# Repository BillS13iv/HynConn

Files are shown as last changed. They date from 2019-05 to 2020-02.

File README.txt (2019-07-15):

NOTICE: I do NOT guarantee anything on this connector.  It is up to you to ensure the fitment, rigidity, and design with your setup.  I take no ownership of any damage you may do.

NOTES ON CONNECTORS: Pricing shown is that at Shapeways.com for Fine Detail Plastic with Smoothest Finish.
Information on the material can be found here: https://www.shapeways.com/materials/fine-detail-plastic.
The polymer (for fine detail plastic) is a poly-acrylic that is rated for 133F (56C), but has poor UV resistance .
It is recommended that if you believe the connector may be exposed to sun light, to coat the outside of the connector in a UV-resistant coating such as Krylons UV-resistant clear coat (https://www.krylon.com/products/uvresistant-clear-coating/).
The .stl files have been optimized and are ready to be sent to a printing service.
The .skp are Sketchup files (version 2018 or later) that can be used to modify the connector if need be.
If you change the connector design, it is recommended to optimize the drawing using a service like those by MakePrintable (https://makeprintable.com/) to optimize the .stl.  You may find this optimization will reduce printing costs significantly.

-----------------------------------------------------------------------------------------

The male connector designed to work with socket strips are also made by SamTec.
You will need:
Quantity: 1, Model: ESQT-108-02-F-S-309
https://www.samtec.com/products/ESQT-108-02-F-S-309
Quantity: 1, Model: MTMM-108-15-T-S-541
https://www.samtec.com/products/mtmm-108-15-t-s-541
Quantity: 2, Model: ESQT-102-02-F-S-309
https://www.samtec.com/products/ESQT-102-02-F-S-309
Quantity: 2, Model: MTMM-102-15-T-S-541
https://www.samtec.com/products/mtmm-102-15-t-s-541

The 7mm end (shorter end) is loaded into the connector.  The longer end is used for connecting wires.

-----------------------------------------------------------------------------------------

The female connector uses receptacles made by TE:
You will need:
Quantity: 14 to 24, Model: 2-1703930-1
https://www.te.com/usa-en/product-2-1703930-1.html

-----------------------------------------------------------------------------------------

For wire, the connectors are desiged for 26 gauge space-saver wire, with an outer diameter of 0.05"
https://www.mcmaster.com/8054t11

Wire Gauge 	26
Current	5 A @ 86° F
Voltage	300V AC
Temperature Range	-40° to 220° F
OD	0.05"

Or for 24 gauge standard wire, with an outer diameter of 0.05"
https://www.mcmaster.com/8251t1

Wire Gauge 	24
Current	7 A @ 86° F
Voltage	300V AC
Temperature Range	-40° to 220° F
OD	0.05"

-----------------------------------------------------------------------------------------

Printing was completed using an outside 3D printing service, I would recommend Shapeways.
Connectors are printed in "Smoothest - Fine Detail Plastic".

-----------------------------------------------------------------------------------------

Older Design: Quantity: 1, Model: MTMM-108-14-T-S-276 Quantity: 2, Model: MTMM-102-14-T-S-276

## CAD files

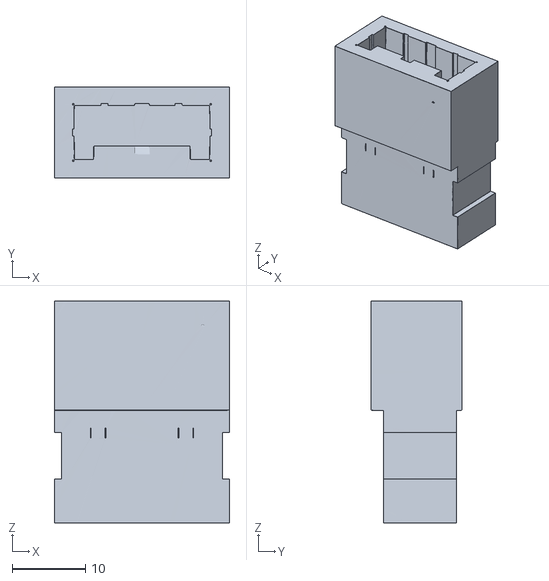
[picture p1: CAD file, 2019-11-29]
Male Connector - Fixed - 11.29.19.stl
24.0 x 12.5 x 30.4

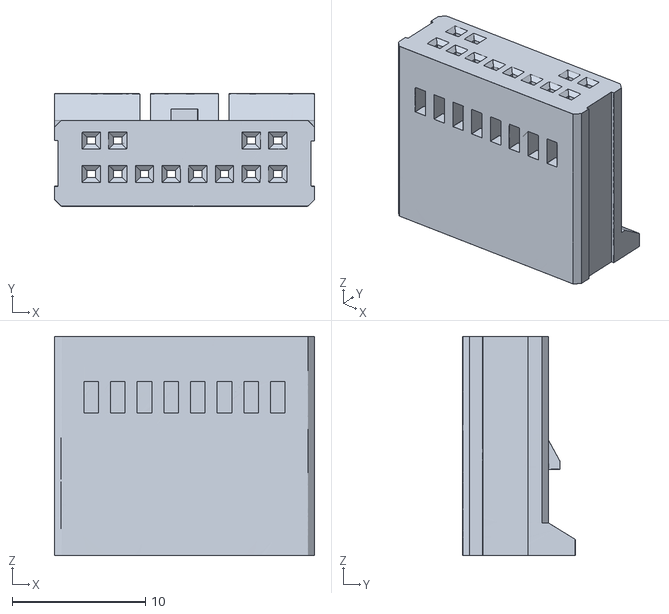
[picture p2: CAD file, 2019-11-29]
Female with Tab - Fixed - 11.29.19.stl
19.5 x 8.44 x 16.5

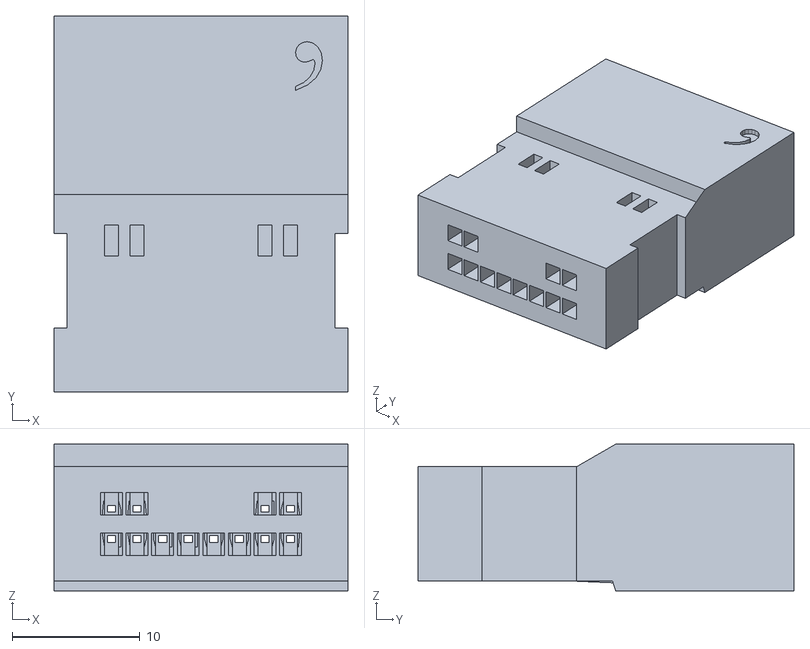
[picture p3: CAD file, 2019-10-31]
Male Connector Socket - With Crimps - 10.31.obj
23.0 x 29.4 x 11.5

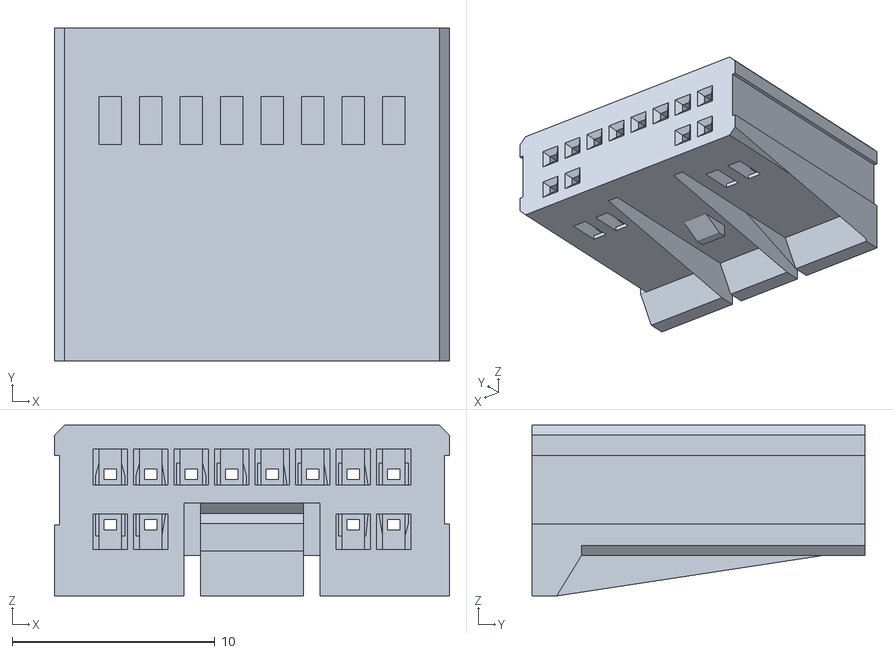
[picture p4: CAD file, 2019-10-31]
Female Connector - Tab - 10.31.19.obj
19.5 x 16.5 x 8.44

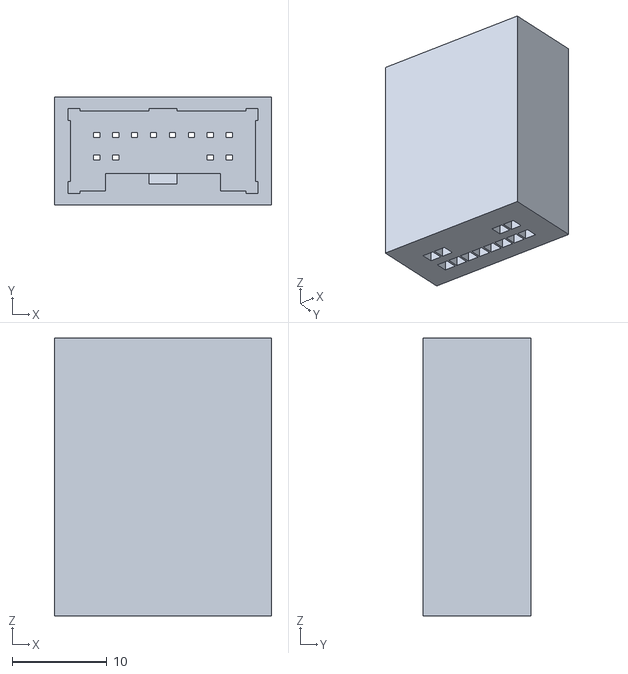
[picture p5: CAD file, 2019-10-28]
Male Connector Socket - Wire Pin Crimps.stl
23.0 x 11.5 x 29.4

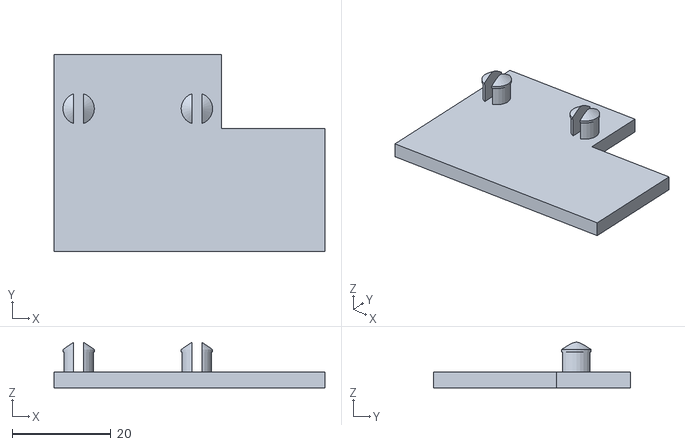
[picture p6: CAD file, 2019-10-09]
New Back Plate.stl
55.0 x 40.0 x 9.27

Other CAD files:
Female Connector - No Tab - 10.31.19.obj
Female with Tab - Fixed - 11.29.19.obj
Male Connector - Fixed - 11.29.19.obj
Male Connector Socket - 4.29.19.skp
Male Connector Socket - With Crimps - 10.31.19.skp

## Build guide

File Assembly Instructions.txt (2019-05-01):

rTools Required:
* A heat gun or hair dryer
* A crimping tool for Dupont pins (a ratcheting set is preferred)
* A set of wire strippers, also a straight pair of tin snips may be useful for cutting pins
* A small metal pick
* 24 gauge wire heat shrink (7 x ½” (13mm) long pieces)

To Note:
The phrase “receptacle” will refer to the part 2-1703930-1, the TE Receptacle Terminal
The phrase “socket head” will refer to parts ESQT-108-02-F-S-309 and ESQT-102-02-F-S-309, made by Samtec
The phrase “terminal head” will refer to parts MTMM-108-15-T-S-541 and MTMM-102-15-T-S-541 made by Samtec

-------------------------------------------------------------------------------

1) Start by cutting the wire into 6” to 12” (15 cm to 30 cm) lengths; a total of strips 14 are needed
2) Strip off 1/8th of an inch of insulation (2.5 mm) on each wire
3) Insert the wire ~7/32” (5.5 mm) onto the wire receptacle
4) Crimp the wire onto the receptacle using the crimping tool
a. NOTE: For the ratcheting crimping tool, it is easiest to close the mouth of the tool until the receptacle barely fits into the teeth.  This will hold the receptacle in place to align the wire and squeeze the tool.
5) Repeat for the other 13 wires
6) Inspect the 3D printed connectors and verify that all the hole are clear.  A 0.197” (0.5 mm) drill bit can be used to clear out any closed holes on the male connector.

Female Connector:
1) Insert the crimped wires into the backside of the 3D printed connectors with the spring portion of the connector facing outward.  Based on what side of the connector you are loading the receptacle, you may have to flip the receptacle
2) Using the pick, push the receptacle to the front of the female housing; there is a small chamber on the housing were the receptacle spring should lift, locking it into place
3) Loosely tug onto the wire to ensure the spring has fully lifted, and the receptacle will not come out of the housing
4) Repeat for the next 6 wires

Male Connector:
1) Inset the socket heads into the backside of the male connector and light push the the the socket heads until the pin are exposed on the front of the male housing, all 3 socket head should be inserted into the housing before continuing
2) Using a padded vise or pushing on the backside of the connector using a surface, continue to move the socket head until only ~1/8” (or 3 mm) remains exposed
3) Place the pieces on heat shrink on the remaining 7 wires, the end of the heat shrink should be flush with the receptacle ends so that the receptacle is fully covered
4) Using the heat gun, shrink the heat shrink onto the receptacle
a. NOTE: This can be done either before or after attaching the connector to terminal heads (step 7).  Caution should be used not to destroy the terminal heads with the heat gun if this is done.
5) Insert the long end of the terminal heads into the socket heads and note the gap between the spacer on the terminal head and the socket head (the gap should be around ~6mm in length or ~1/4”)
6) Remove the terminal heads from the socket heads, and using the wire cutters or tin snips, cut the pins to remove the gap distance (between 5 and 8 mm)
7) Attach the receptacles to the uncut end of the terminal head pins
8) Reinsert the cut end of the terminal head back into the socket head
9) Use a heat resistant, non-expanding glue to secure all components (terminal heads, socket heads, receptacles).

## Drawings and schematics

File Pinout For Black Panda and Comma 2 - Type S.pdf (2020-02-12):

# Type S KET

## GRND

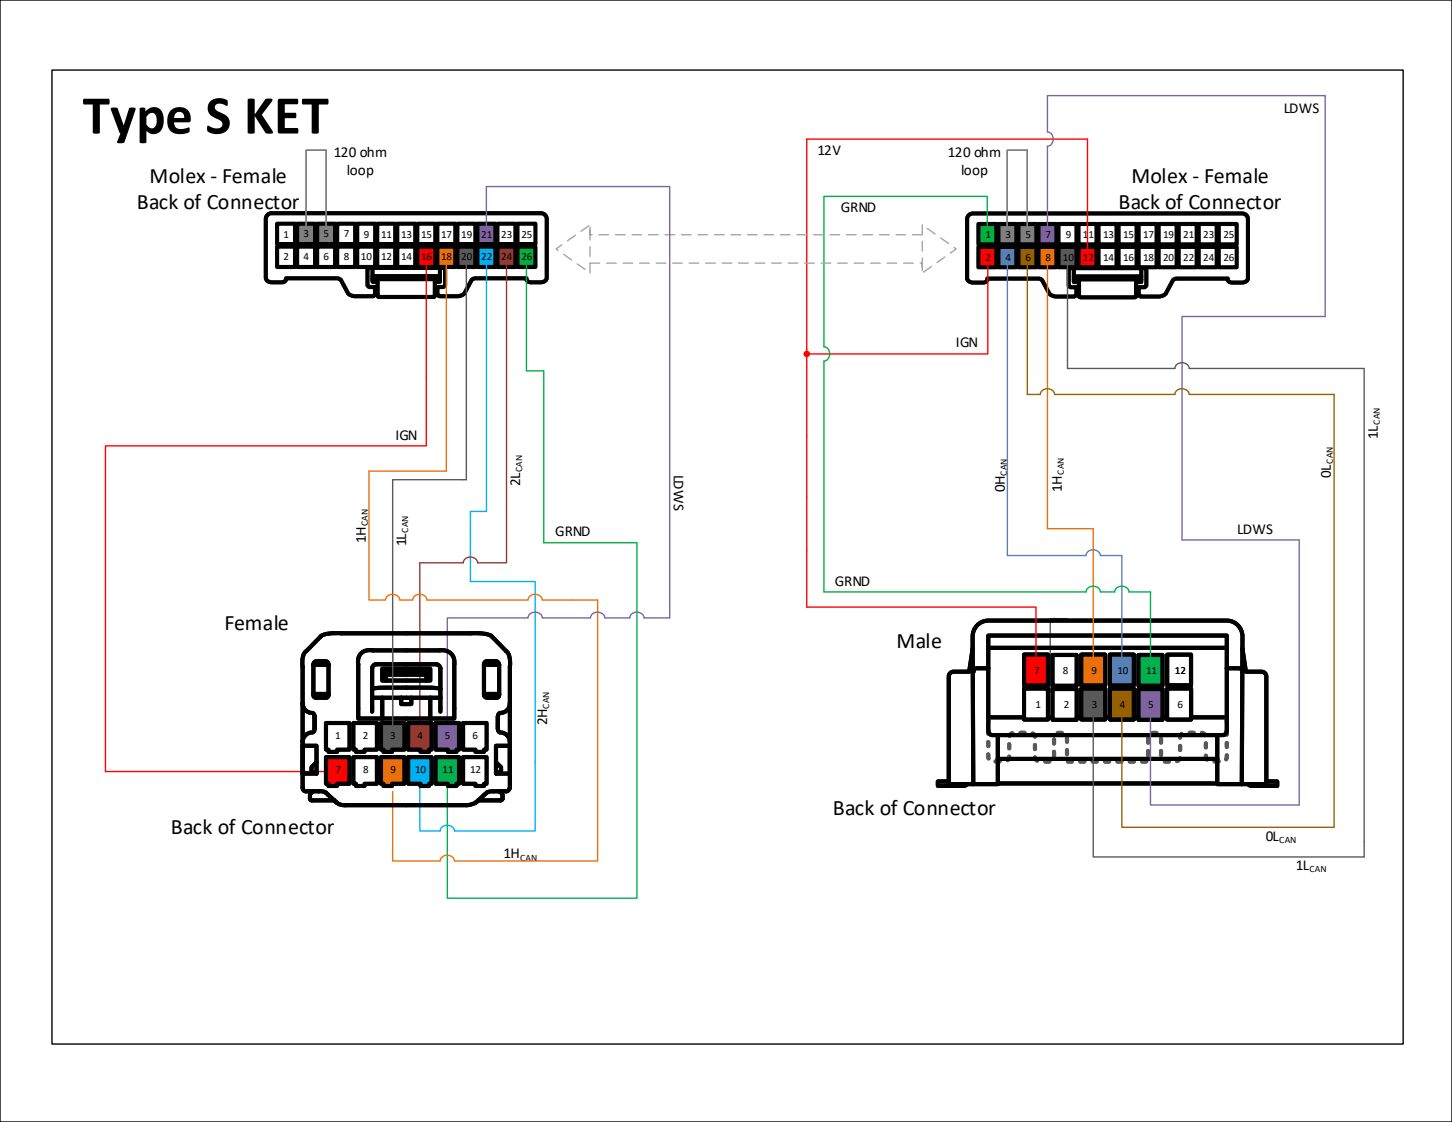
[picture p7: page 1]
GRND; IGN1LCAN; IGN; Female; Male; 120 ohm loop; LDWS; 1HCAN; 2HCAN; 2LCAN; 0LCAN; 1LCAN; 0HCAN

Molex - Female
Back of Connector

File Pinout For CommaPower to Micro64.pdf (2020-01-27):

# Comma Power RJ45 to Micro 64 8W

## IGN

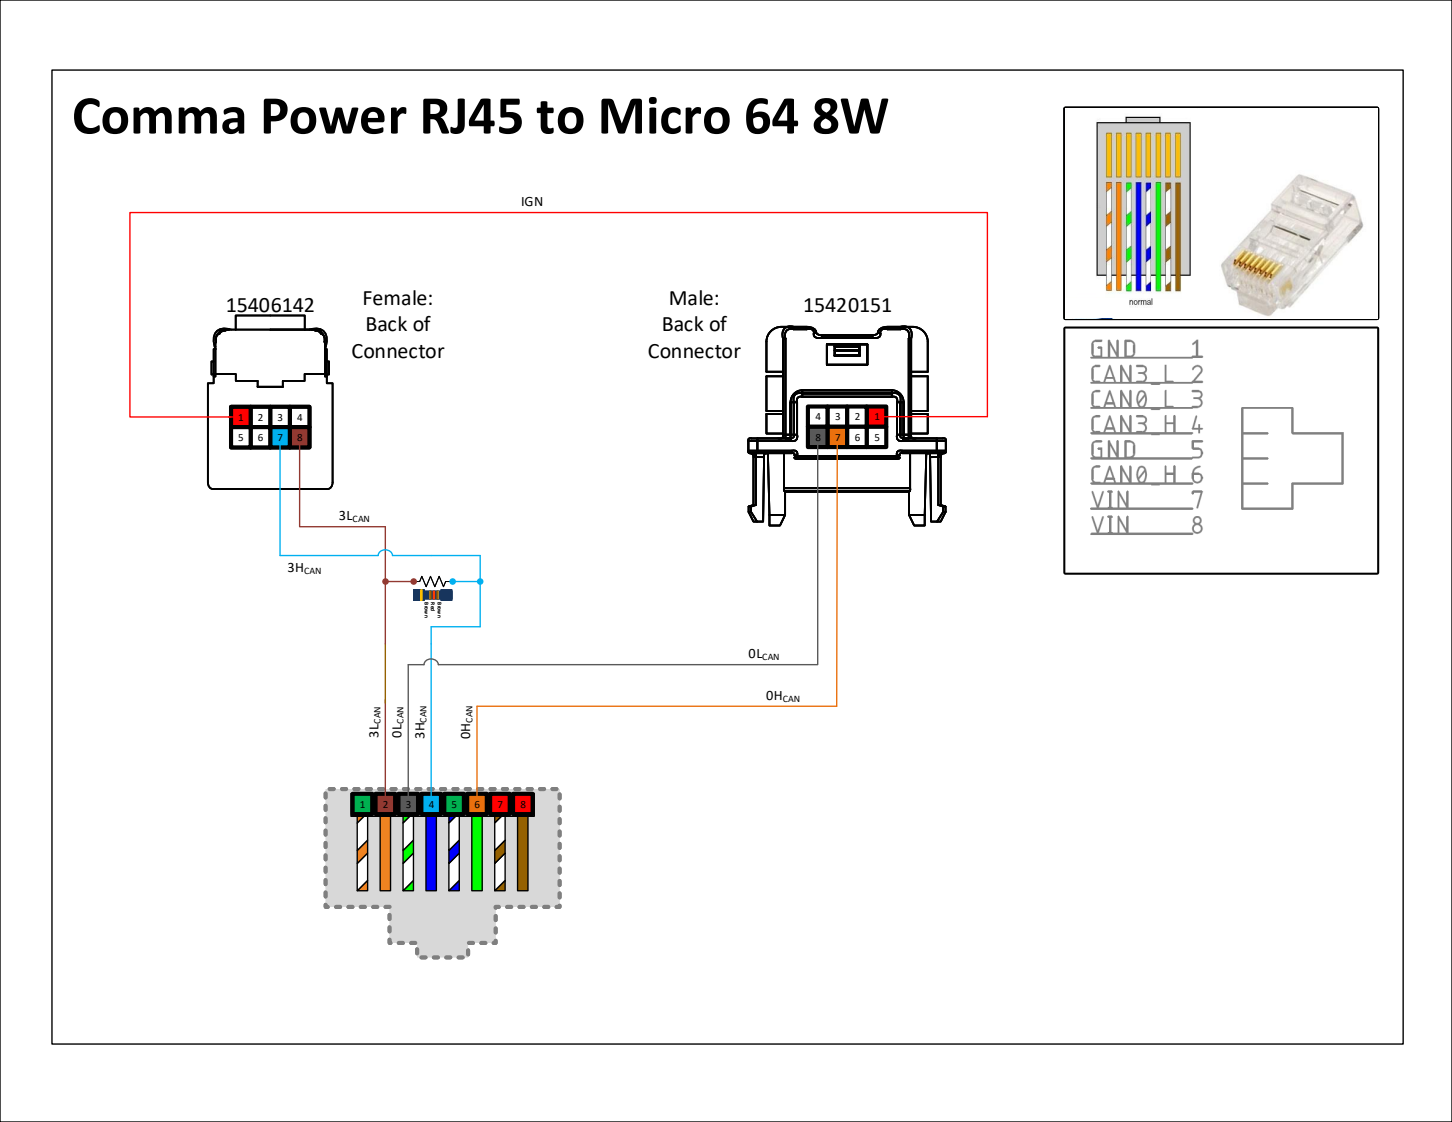
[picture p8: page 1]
8 ³LCAN; 0LCAN; 3HCAN; 0HCAN; 3LCAN; Male: Back of Connector

Female:
Back of
Connector Brown Red Brown

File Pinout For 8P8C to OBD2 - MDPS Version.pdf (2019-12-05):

# 8P8C to OBD2 – MDPS Version

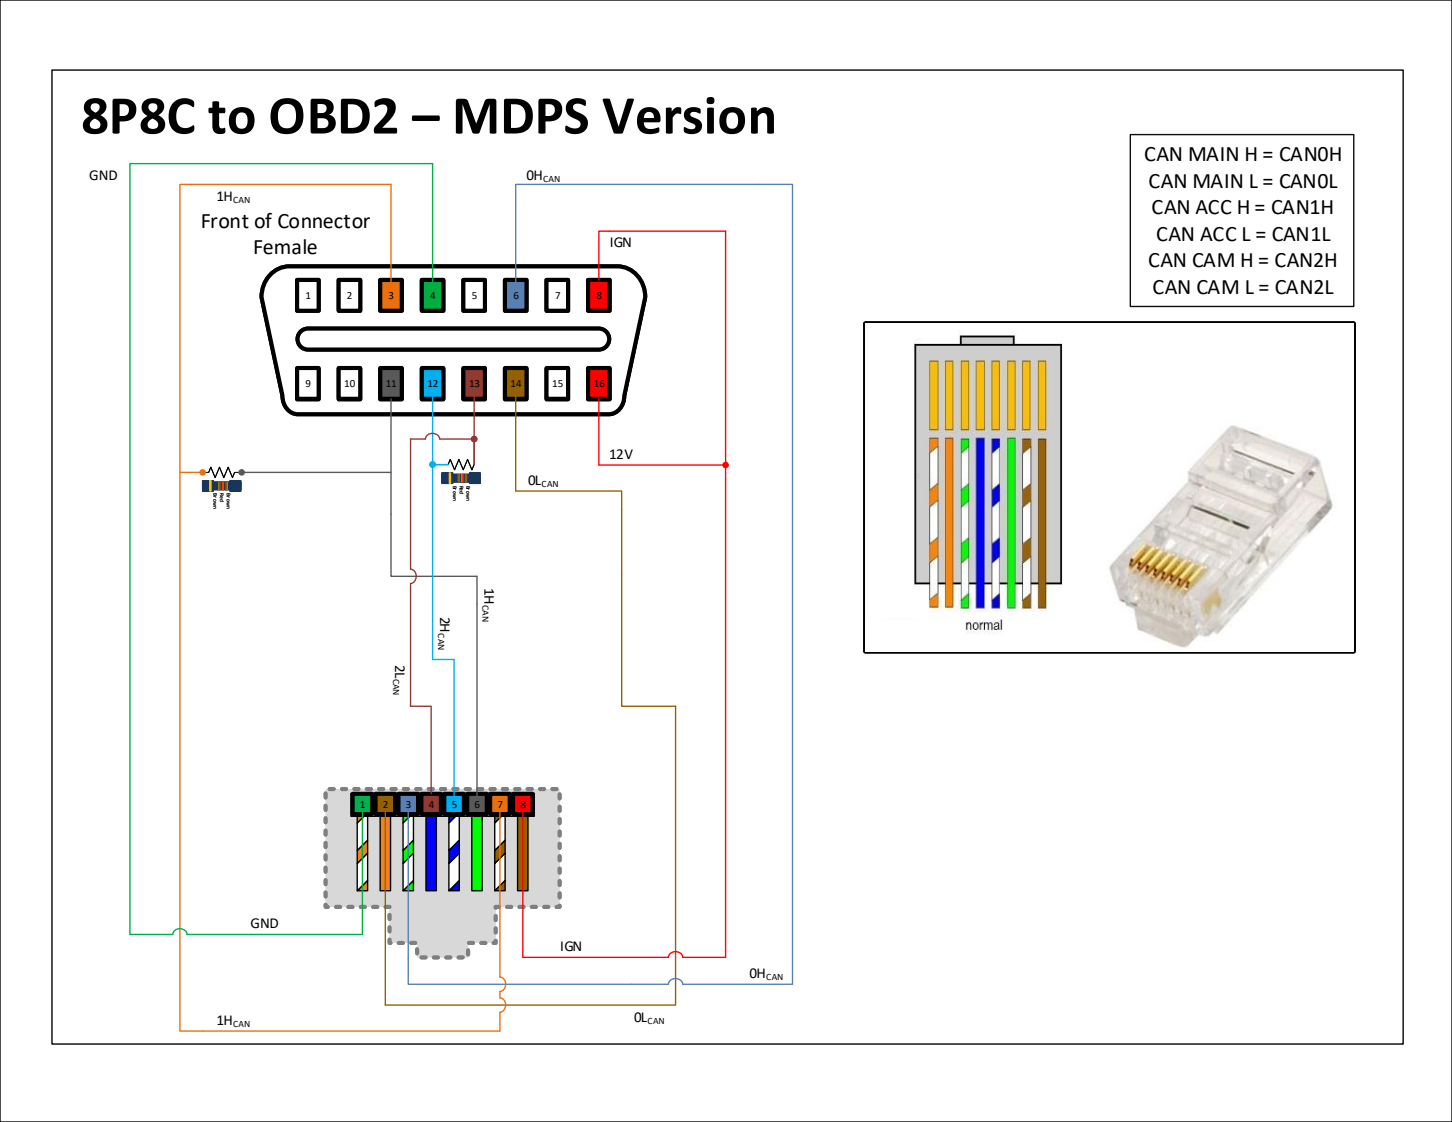
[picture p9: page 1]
CAN MAIN H = CAN0H CAN MAIN L = CAN0L CAN ACC H = CAN1H CAN ACC L = CAN1L CAN CAM H = CAN2H CAN CAM L = CAN2L; IGN; 8 Br own Red Br own; Front of Connector Female; 1HCAN; 0HCAN; 0LCAN; GND; 2LCAN; 2HCAN; Br own; Red

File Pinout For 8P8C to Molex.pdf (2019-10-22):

# 8P8C to Molex

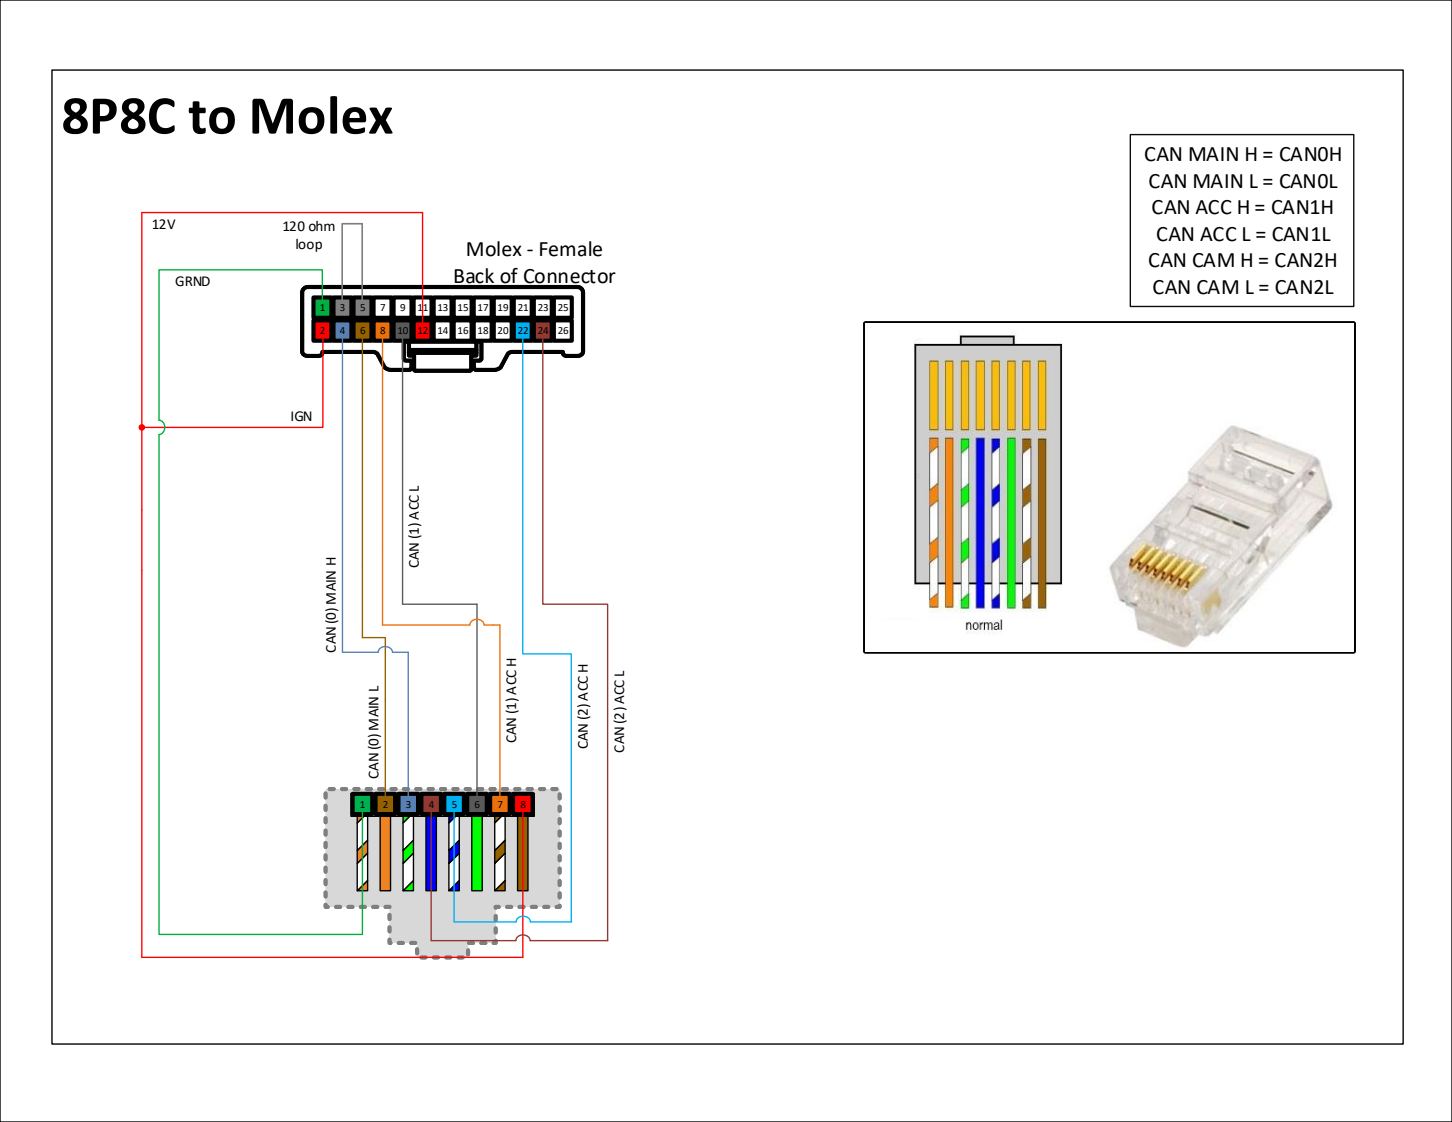
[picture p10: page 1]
CAN MAIN H = CAN0H CAN MAIN L = CAN0L CAN ACC H = CAN1H CAN ACC L = CAN1L CAN CAM H = CAN2H CAN CAM L = CAN2L; GRND; IGN; - Female; CAN (1) ACC L; CAN (0) MAIN L; CAN (2) ACC H; CAN (0) MAIN H; 120 ohm loop; CAN (1) ACC H; CAN (2) ACC L

Molex
Back of Connector

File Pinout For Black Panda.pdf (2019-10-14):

# Type I KET

## GRND

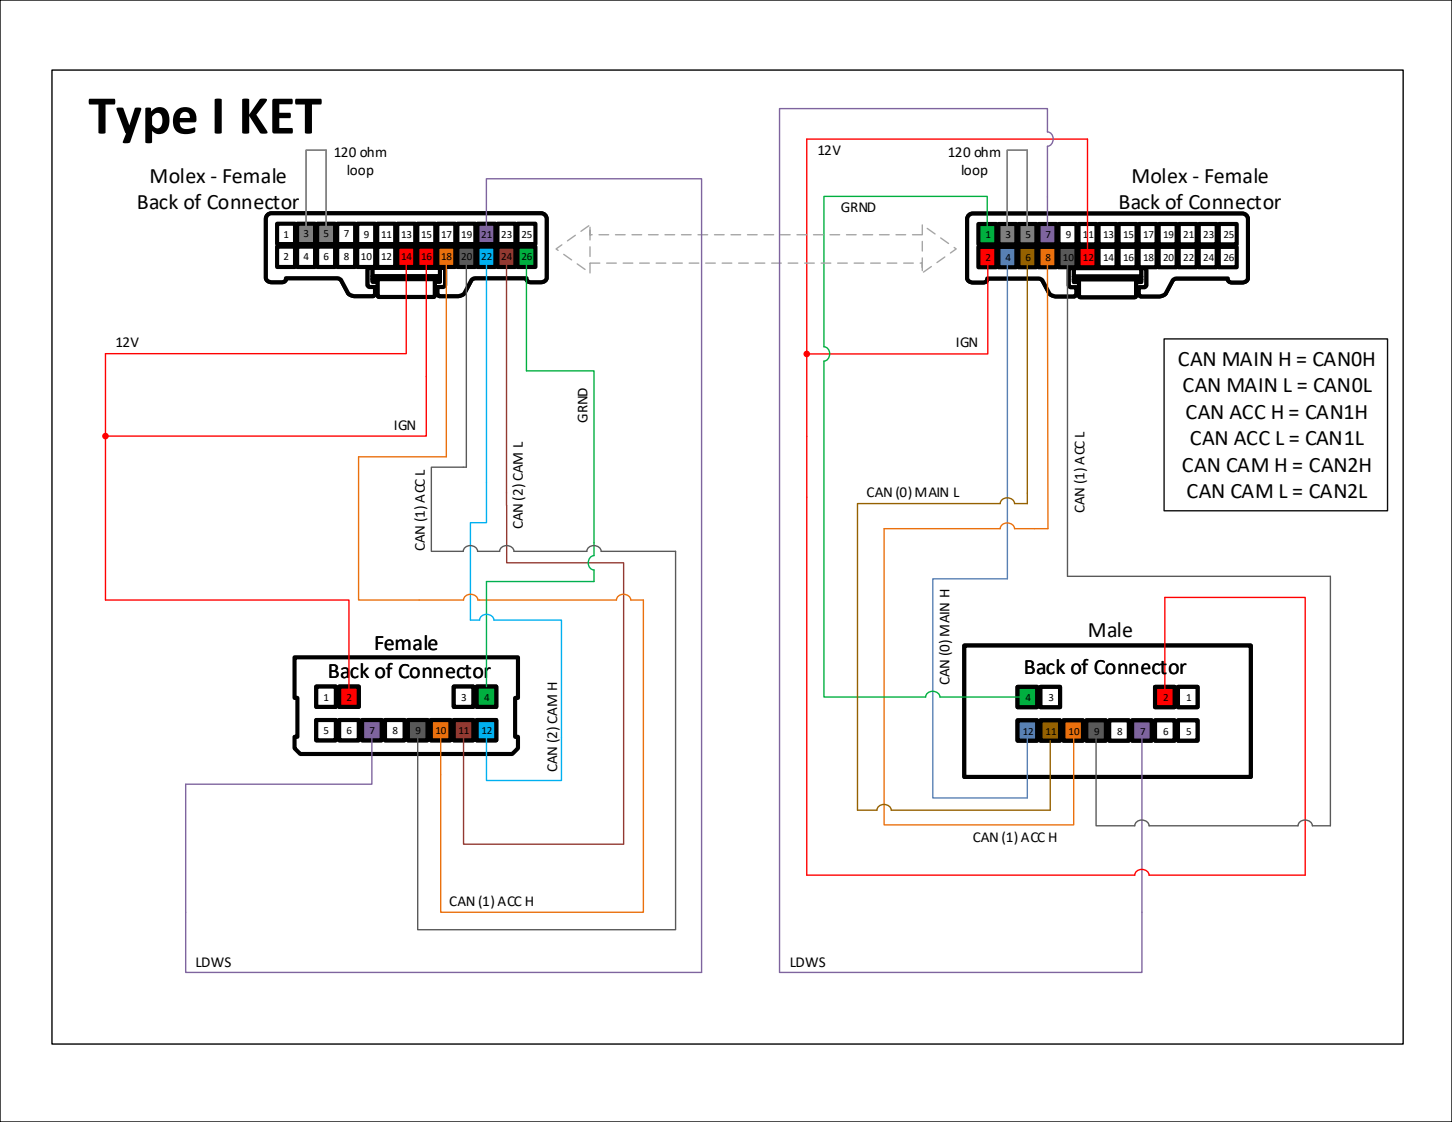
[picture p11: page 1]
CAN MAIN H = CAN0H CAN MAIN L = CAN0L CAN ACC H = CAN1H CAN ACC L = CAN1L CAN CAM H = CAN2H CAN CAM L = CAN2L; GRND; IGN; CAN (2) CAM H; CAN (1) ACC H; CAN (1) ACC L; CAN (2) CAM L; CAN (0) MAIN L; CAN (0) MAIN H; Female; Male; Back of Connector; 120 ohm loop; LDWS

Molex - Female
Back of Connector

# Type II KET

## GRND

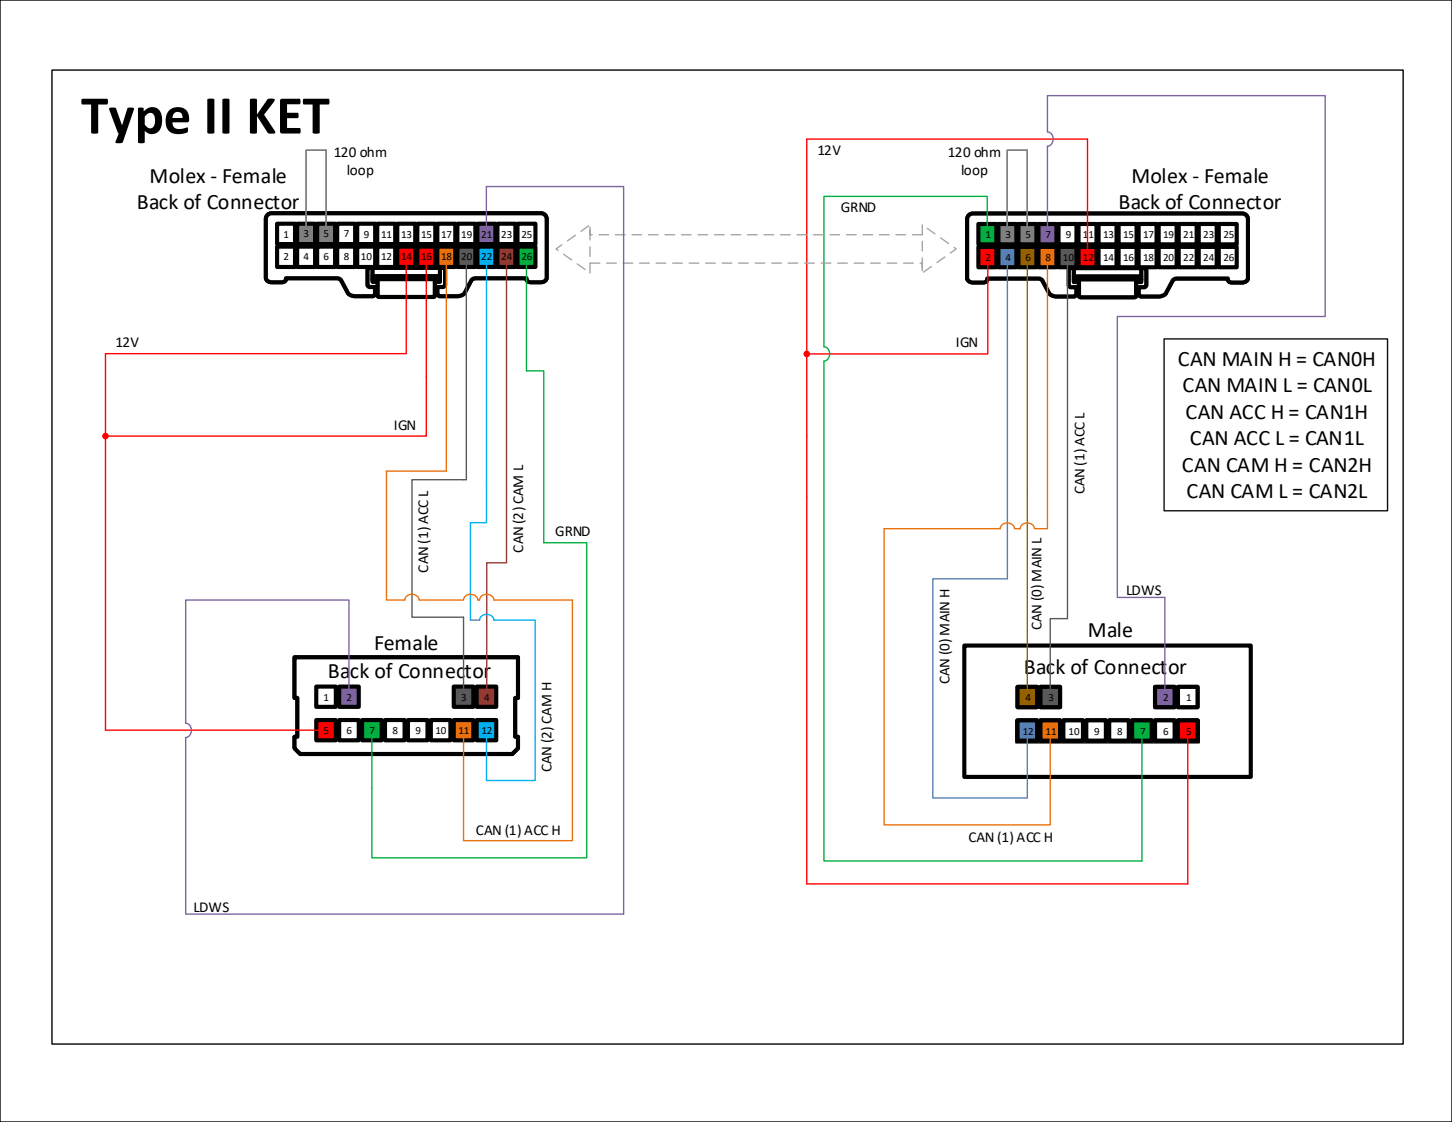
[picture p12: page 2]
GRND; IGN; CAN (2) CAM H; CAN (1) ACC H; CAN (1) ACC L; CAN (2) CAM L; CAN (0) MAIN L; CAN (0) MAIN H; Female; Male; 120 ohm loop; CAN MAIN H = CAN0H CAN MAIN L = CAN0L CAN ACC H = CAN1H CAN ACC L = CAN1L CAN CAM H = CAN2H CAN CAM L = CAN2L; LDWS

Molex - Female
Back of Connector

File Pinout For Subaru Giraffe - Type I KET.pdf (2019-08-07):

# Type I KET

## GRND

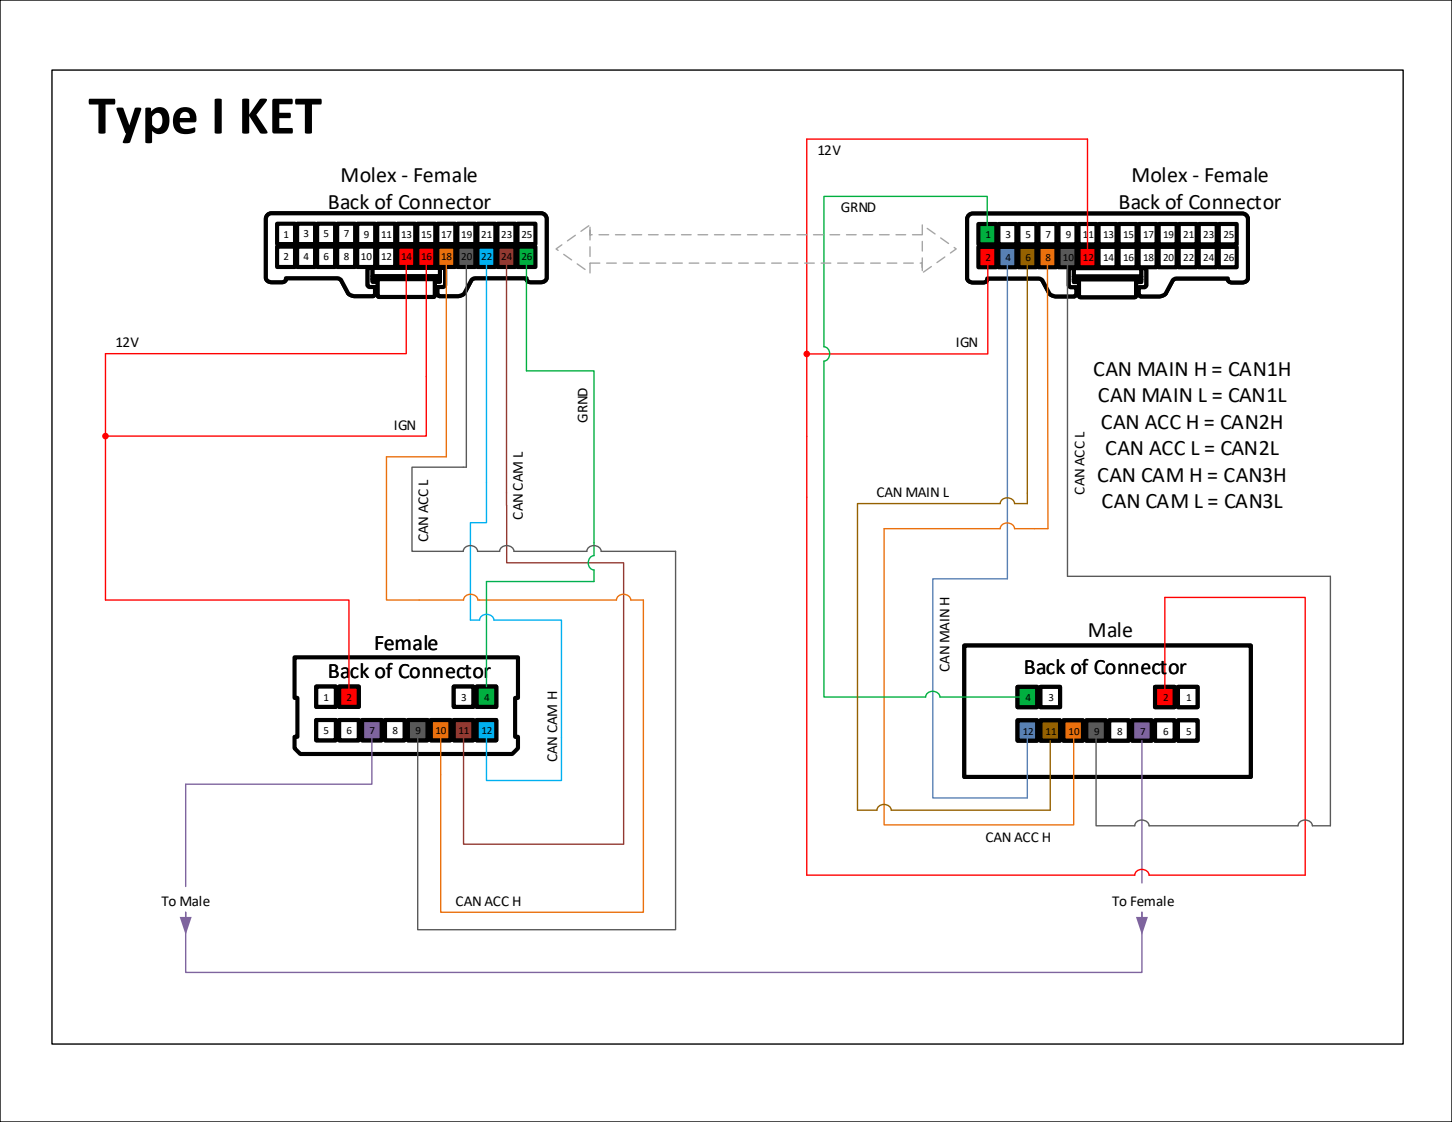
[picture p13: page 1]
CAN MAIN H = CAN1H CAN MAIN L = CAN1L CAN ACC H = CAN2H CAN ACC L = CAN2L CAN CAM H = CAN3H CAN CAM L = CAN3L; GRND; IGN; To Male; CAN CAM H; CAN ACC H; CAN ACC L; CAN CAM L; CAN MAIN L; CAN MAIN H; To Female; Female; Male; Back of Connector

Molex - Female
Back of Connector

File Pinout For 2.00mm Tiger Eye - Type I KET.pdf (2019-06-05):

# CAN2H Type I KET

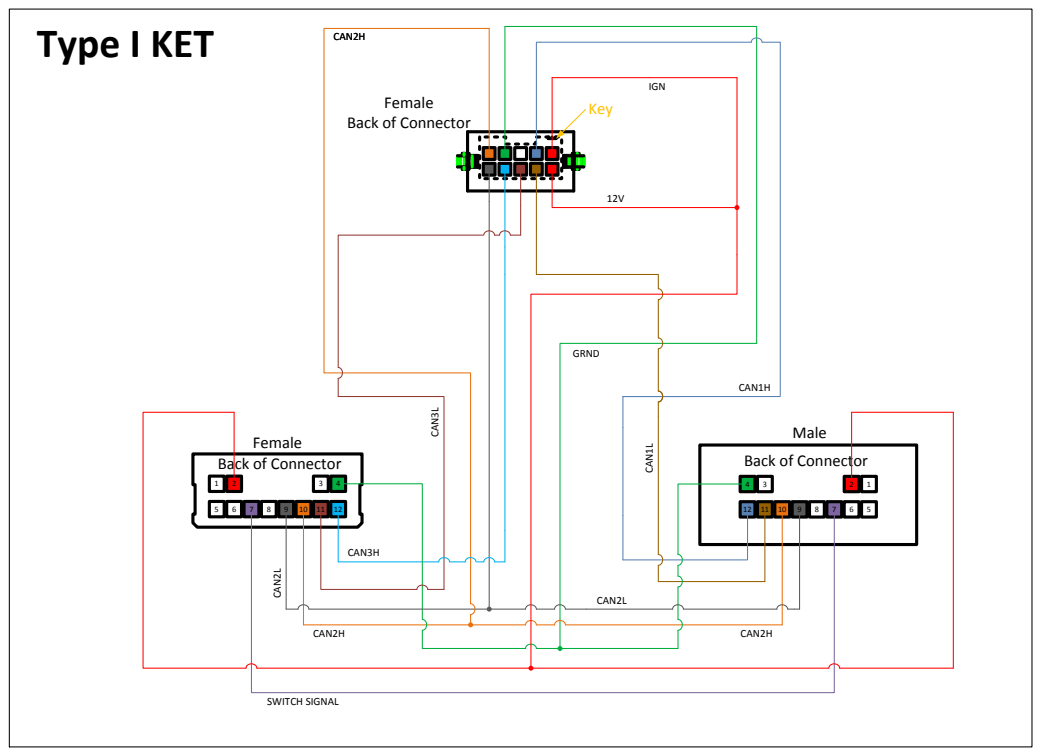
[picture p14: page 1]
3 Back of Connector; Back of Connector; Female; Male; CAN2L CAN²L; CAN2H; CAN3H; CAN¹L GRND; IGN; CAN3L; CAN1H; Key; SWITCH SIGNAL

Female
Back of Connector

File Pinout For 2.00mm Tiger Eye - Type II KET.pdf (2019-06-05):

# Type II KET

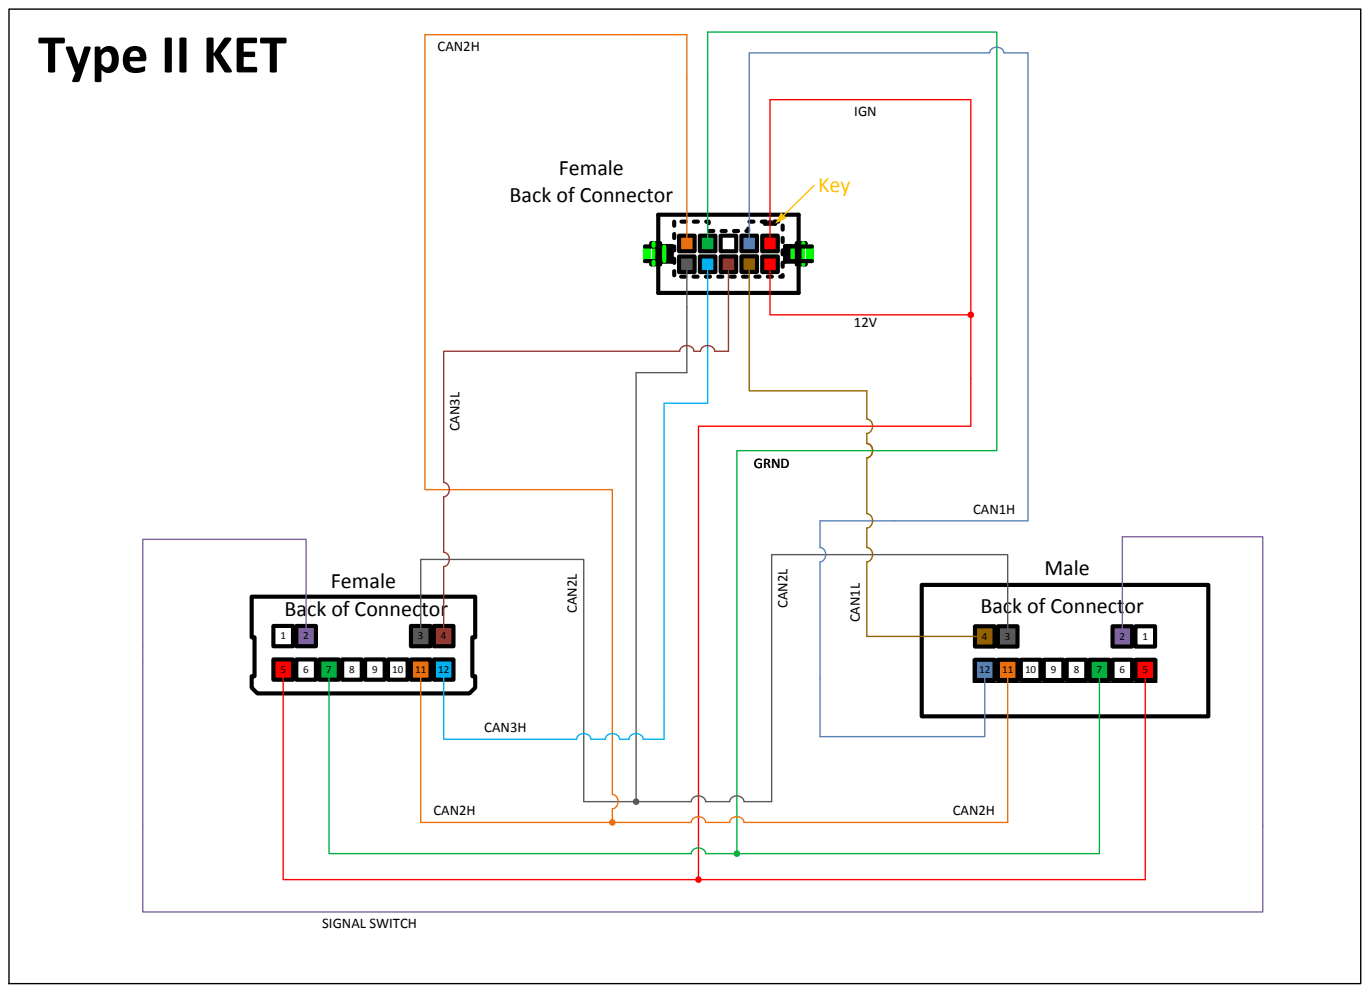
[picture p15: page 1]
4 Back of Connector; GRND; Female; Male CAN²L; CAN2L; CAN2H; CAN1H CAN¹L; SIGNAL SWITCH; CAN3H; IGN; CAN3L Female; Back of Connector; Key; Brown Red; Brown

Back of Connector

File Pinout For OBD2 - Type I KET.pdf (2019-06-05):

# CAN2H Type I KET

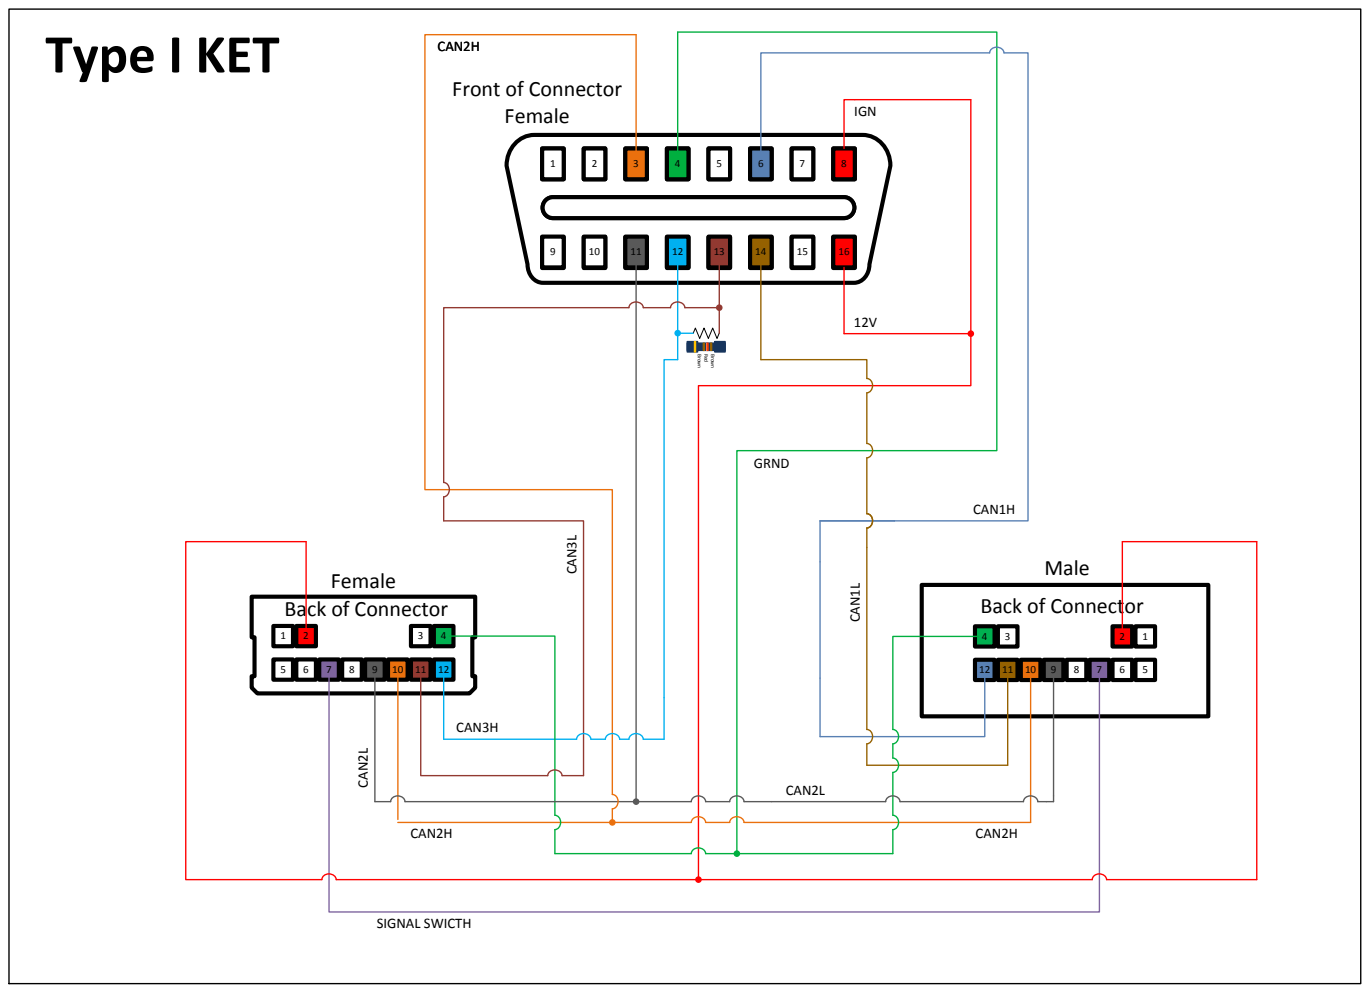
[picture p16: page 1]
3 Back of Connector; Back of Connector; Female; Male; CAN2L CAN²L; CAN2H; CAN3H; CAN¹L GRND; IGN; 8 CAN2H; Brown Red; Brown CAN3L; CAN1H; SIGNAL SWICTH

Front of Connector
Female

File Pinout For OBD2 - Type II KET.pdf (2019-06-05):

# Type II KET

## IGN

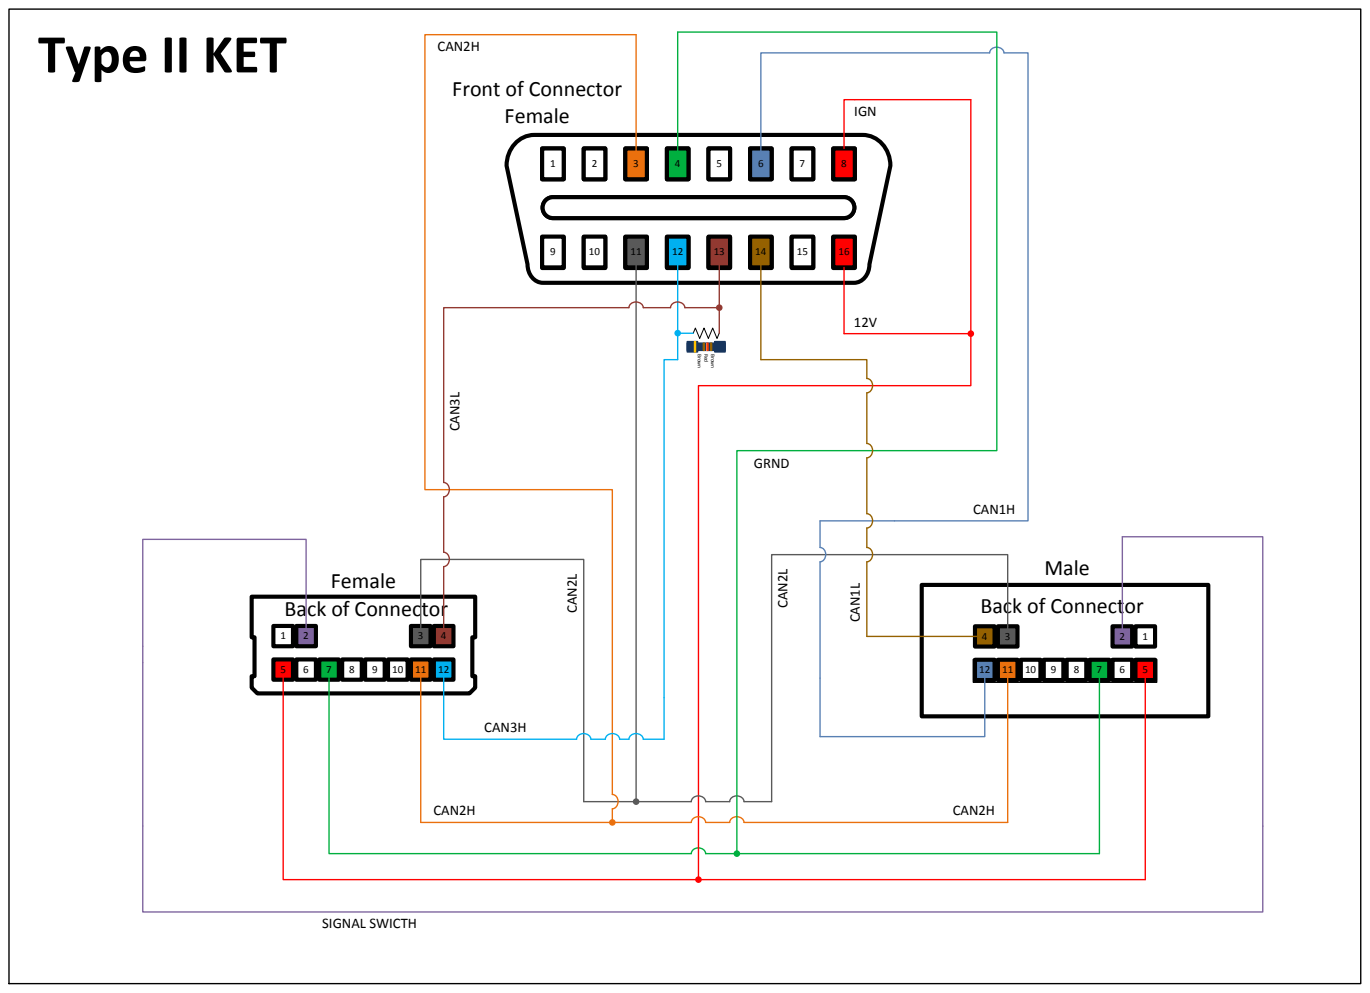
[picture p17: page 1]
4 Back of Connector; GRND; Female; 8 CAN2H; Brown Red; Brown CAN2L; CAN2L; CAN2H; CAN3L; CAN1H CAN¹L; SIGNAL SWICTH; CAN3H

Front of Connector
Female

Male
Back of Connector

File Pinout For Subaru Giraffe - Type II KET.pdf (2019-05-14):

# Type II KET

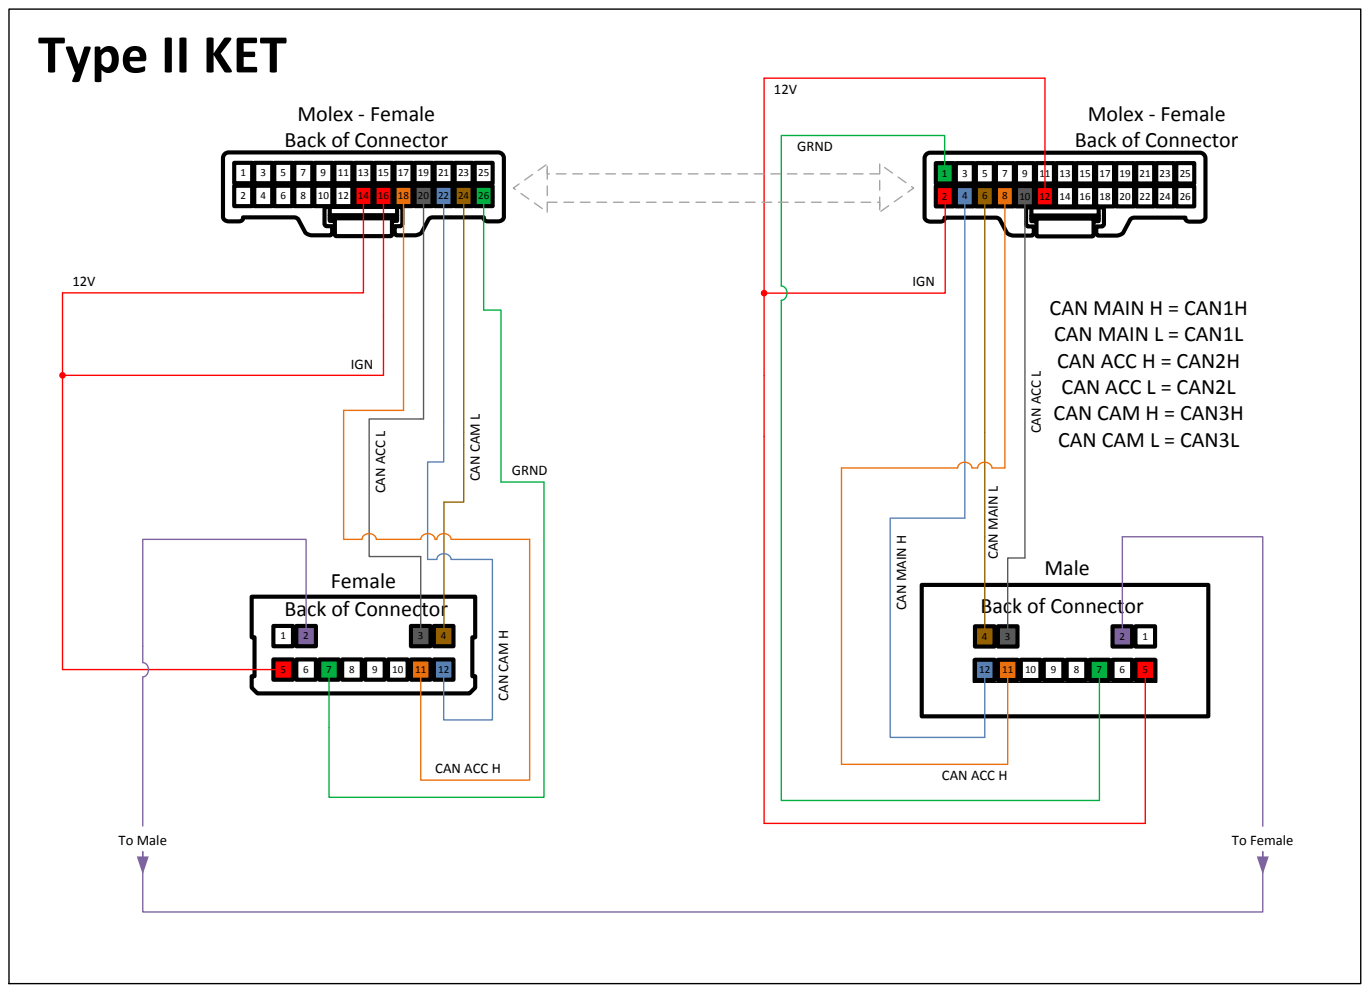
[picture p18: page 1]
CAN MAIN H = CAN1H CAN MAIN L = CAN1L CAN ACC H = CAN2H CAN ACC L = CAN2L CAN CAM H = CAN3H CAN CAM L = CAN3L; 4 Back of Connector; GRND; IGN; To Male; CAN ACC L; CAN CAM L; 1 GRND; CAN MAIN H; To Female; Female

Molex - Female
Back of Connector

CAN ACC L CAN MAIN L CAN ACC H

Male

CAN CAM H CAN ACC H

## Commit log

2019-03-27 Add files via upload
    Sketchup files of latest connector designs
    [Male Connector 3.28.19.skp]
2019-05-01 Update Assembly Instructions.txt

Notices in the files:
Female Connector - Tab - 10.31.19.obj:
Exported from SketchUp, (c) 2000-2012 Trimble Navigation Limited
